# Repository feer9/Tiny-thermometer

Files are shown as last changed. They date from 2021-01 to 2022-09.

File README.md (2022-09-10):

# Tiny-thermomether

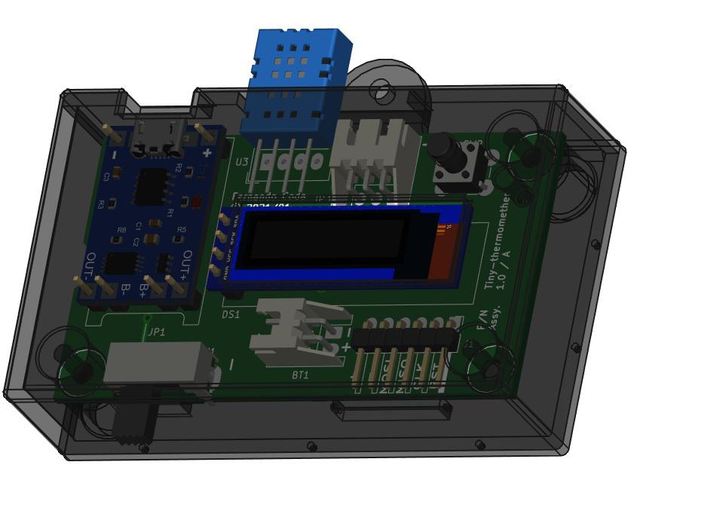
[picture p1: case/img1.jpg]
 

This project is mostly a recopilation of other projects I've found on various pages.  
I've just joined them at my personal taste, so I'll let the link to those projects below.  

## Parts used

+ ATtiny85
+ SSD1306 128x32 OLED I2C Display
+ DHT11 temperature and humidity sensor
+ DS18B20 water temperature sensor

## Electrical connection

ATtiny85  | PCB                   | Debug
--------- | --------------------- | --------
PB0       | Display SDA           | MOSI
PB1       | Push button           | MISO
PB2       | Display SCL           | CLK
PB3       | DHT11 (pin 2)         |
PB4       | DS18B20 (yellow wire) |
PB5       | N/C                   | RST

The sensors data lines have a 4.7K PullUp resistor.  
The push button have a 10K resistor.  
The I2C bus have a 10K PullUp resistor, both in SDA and SCL.

## Compilation and flashing

I've only tested it with avr-gcc on linux.  
To compile you need `avr-gcc` and `avr-g++`.  
To flash it I've used `avrdude` with an `usbasp-clone` avr programmer from [this other project](https://github.com/feer9/FASTUSBasp) running on an STM32F407VET6.  
Running `make flash` will compile and flash the program, but the first time you can `make install` to flash the program and fuses to match the clock speed.  

## Code included in this project:

https://www.instructables.com/ATTiny85-connects-to-I2C-OLED-display-Great-Things/

https://github.com/Jacajack/avr-ds18b20

https://www.hackster.io/boyanov/tinudht-c-library-for-dht11-temperature-humidity-sensor-c492e9

## Other pages of utility:

https://github.com/lexus2k/ssd1306

https://aprendiendoarduino.wordpress.com/2016/11/14/bus-i2ctwi/

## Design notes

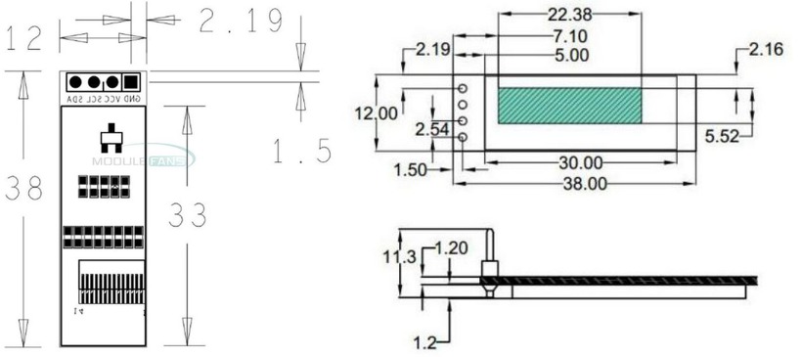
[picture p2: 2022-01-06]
pcb/doc/ssd1306_oled/oled_pcb_dimensions_2.jpeg

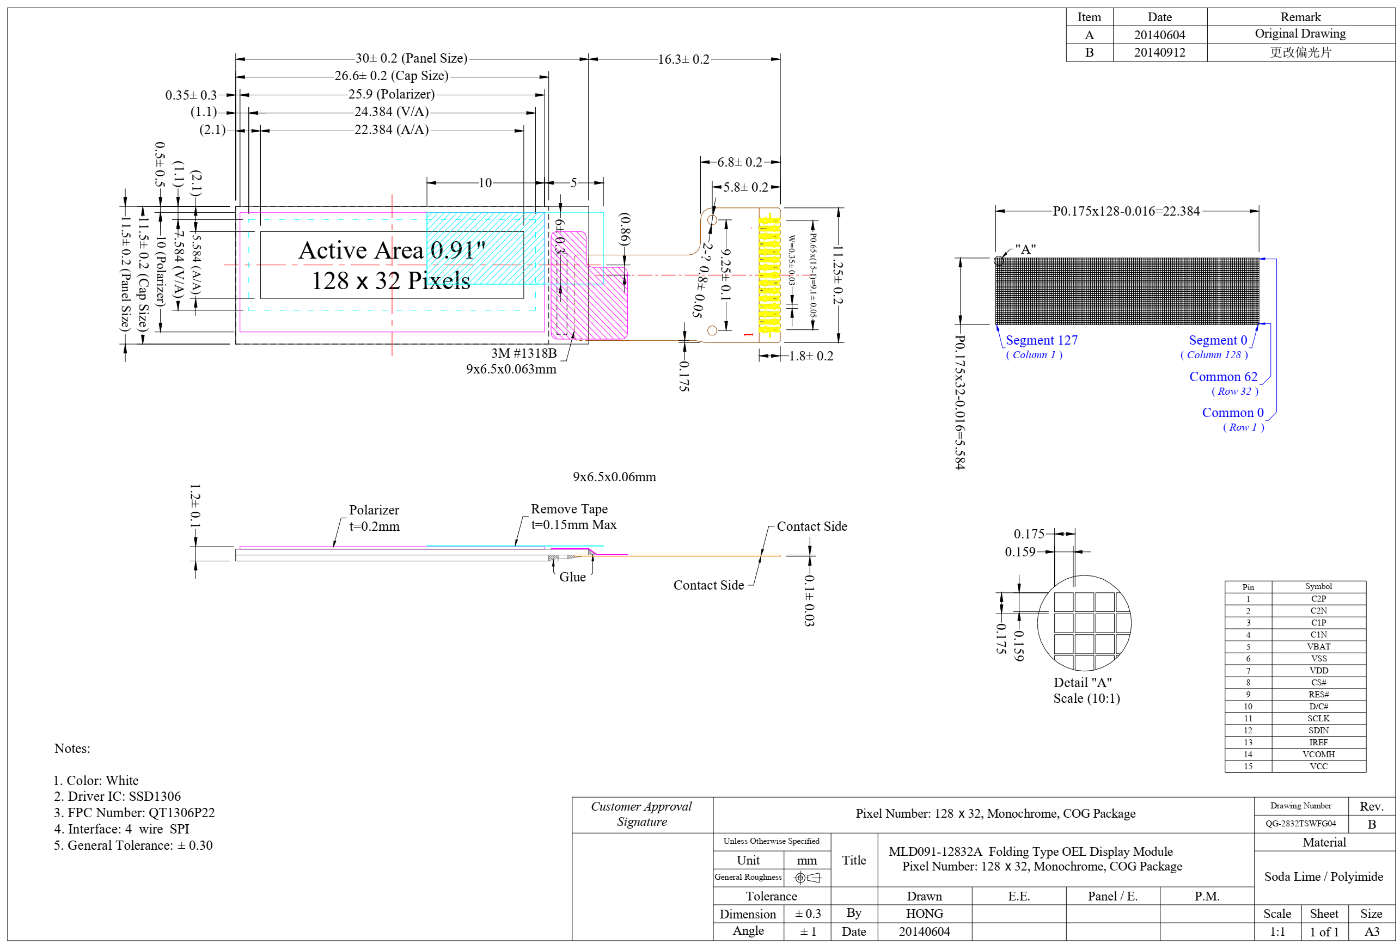
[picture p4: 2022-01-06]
pcb/doc/ssd1306_oled/oled_dimensions.png

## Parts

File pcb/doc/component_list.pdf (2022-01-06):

Tiny-thermomether

Source:
Date: | sáb 13 mar 2021 17:37:19
Tool: | Eeschema 5.1.9
Generator: | /usr/share/kicad/plugins/bom_csv_grouped_by_value.py

15

Individual Components:

Item | Qty | Reference(s) Value
BT1 | Battery_Cell
C1 | 0.1uF
DS1 | SSD1306_128x32
J1 | Conn_01x06_Male
R1 | 10k
R2 | 10k
R3 | 4k7
R4 | 4k7
R5 | 10k
SW1 | SW_SPDT
SW2 | SW_Push
U1 | TP4056
U2 | ATtiny85-20SU
U3 | DHT11
U4 | DS18B20

Collated Components:

Item | Qty | Reference(s) Value
1 | 1 | BT1 | Battery_Cell
2 | 1 | C1 | 0.1uF
3 | 1 | DS1 | SSD1306_128x32
4 | 1 | J1 | Conn_01x06_Male
5 | 3 | R1, R2, R5 10k
6 | 2 | R3, R4 | 4k7
7 | 1 | SW1 | SW_SPDT
8 | 1 | SW2 | SW_Push
9 | 1 | U1 | TP4056
10 | 1 | U2 | ATtiny85-20SU
11 | 1 | U3 | DHT11
12 | 1 | U4 | DS18B20

/run/media/Datos/Feer/OneDrive - est.frba.utn.edu.ar/pcbs/attiny85/Tiny-thermomether/Tiny-thermomether.sch

Component
Count:

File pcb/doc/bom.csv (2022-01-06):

Source: | /run/media/Datos/Feer/OneDrive - est.frba.utn.edu.ar/pcbs/attiny85/Tiny-thermomether/Tiny-thermomether.sch
Date: | sáb 13 mar 2021 17:37:19
Tool: | Eeschema 5.1.9
Generator: | /usr/share/kicad/plugins/bom_csv_grouped_by_value.py
Component Count: | 15
Individual Components:
Item | Qty | Reference(s) | Value | LibPart | Footprint | Datasheet
 |  | BT1 | Battery_Cell | Device:Battery_Cell | Connector_JST:JST_XH_S2B-XH-A_1x02_P2.50mm_Horizontal | ~
 |  | C1 | 0.1uF | Device:C | Capacitor_SMD:C_1206_3216Metric_Pad1.33x1.80mm_HandSolder | ~
 |  | DS1 | SSD1306_128x32 | ssd1306_128x32:SSD1306_128x32 | ssd1306:SSD1306_128x32 | https://www.digchip.com/datasheets/parts/datasheet/1121/AG-12864E-pdf.php
 |  | J1 | Conn_01x06_Male | Connector:Conn_01x06_Male | Connector_PinHeader_2.54mm:PinHeader_1x06_P2.54mm_Horizontal | ~
 |  | R1 | 10k | Device:R | Resistor_SMD:R_1206_3216Metric_Pad1.30x1.75mm_HandSolder | ~
 |  | R2 | 10k | Device:R | Resistor_SMD:R_1206_3216Metric_Pad1.30x1.75mm_HandSolder | ~
 |  | R3 | 4k7 | Device:R | Resistor_SMD:R_1206_3216Metric_Pad1.30x1.75mm_HandSolder | ~
 |  | R4 | 4k7 | Device:R | Resistor_SMD:R_1206_3216Metric_Pad1.30x1.75mm_HandSolder | ~
 |  | R5 | 10k | Device:R | Resistor_SMD:R_1206_3216Metric_Pad1.30x1.75mm_HandSolder | ~
 |  | SW1 | SW_SPDT | Switch:SW_SPDT | Button_Switch_THT:SW_SPDT_Angled_P3mm_13x5.5x6mm | ~
 |  | SW2 | SW_Push | Switch:SW_Push | Button_Switch_THT:SW_PUSH_6mm_H7.3mm | ~
 |  | U1 | TP4056 | tp4056:TP4056 | tp4056:TP4056
 |  | U2 | ATtiny85-20SU | MCU_Microchip_ATtiny:ATtiny85-20SU | Package_SO:SOIJ-8_5.3x5.3mm_P1.27mm | http://ww1.microchip.com/downloads/en/DeviceDoc/atmel-2586-avr-8-bit-microcontroller-attiny25-attiny45-attiny85_datasheet.pdf
 |  | U3 | DHT11 | Sensor:DHT11 | Sensor:Aosong_DHT11_5.5x12.0_P2.54mm_horizontal | http://akizukidenshi.com/download/ds/aosong/DHT11.pdf
 |  | U4 | DS18B20 | Sensor_Temperature:DS18B20 | Connector_JST:JST_XH_S3B-XH-A_1x03_P2.50mm_Horizontal | http://datasheets.maximintegrated.com/en/ds/DS18B20.pdf
Collated Components:
Item | Qty | Reference(s) | Value | LibPart | Footprint | Datasheet
1 | 1 | BT1 | Battery_Cell | Device:Battery_Cell | Connector_JST:JST_XH_S2B-XH-A_1x02_P2.50mm_Horizontal | ~
2 | 1 | C1 | 0.1uF | Device:C | Capacitor_SMD:C_1206_3216Metric_Pad1.33x1.80mm_HandSolder | ~
3 | 1 | DS1 | SSD1306_128x32 | ssd1306_128x32:SSD1306_128x32 | ssd1306:SSD1306_128x32 | https://www.digchip.com/datasheets/parts/datasheet/1121/AG-12864E-pdf.php
4 | 1 | J1 | Conn_01x06_Male | Connector:Conn_01x06_Male | Connector_PinHeader_2.54mm:PinHeader_1x06_P2.54mm_Horizontal | ~
5 | 3 | R1, R2, R5 | 10k | Device:R | Resistor_SMD:R_1206_3216Metric_Pad1.30x1.75mm_HandSolder | ~
6 | 2 | R3, R4 | 4k7 | Device:R | Resistor_SMD:R_1206_3216Metric_Pad1.30x1.75mm_HandSolder | ~
7 | 1 | SW1 | SW_SPDT | Switch:SW_SPDT | Button_Switch_THT:SW_SPDT_Angled_P3mm_13x5.5x6mm | ~
8 | 1 | SW2 | SW_Push | Switch:SW_Push | Button_Switch_THT:SW_PUSH_6mm_H7.3mm | ~
9 | 1 | U1 | TP4056 | tp4056:TP4056 | tp4056:TP4056
10 | 1 | U2 | ATtiny85-20SU | MCU_Microchip_ATtiny:ATtiny85-20SU | Package_SO:SOIJ-8_5.3x5.3mm_P1.27mm | http://ww1.microchip.com/downloads/en/DeviceDoc/atmel-2586-avr-8-bit-microcontroller-attiny25-attiny45-attiny85_datasheet.pdf
11 | 1 | U3 | DHT11 | Sensor:DHT11 | Sensor:Aosong_DHT11_5.5x12.0_P2.54mm_horizontal | http://akizukidenshi.com/download/ds/aosong/DHT11.pdf
12 | 1 | U4 | DS18B20 | Sensor_Temperature:DS18B20 | Connector_JST:JST_XH_S3B-XH-A_1x03_P2.50mm_Horizontal | http://datasheets.maximintegrated.com/en/ds/DS18B20.pdf

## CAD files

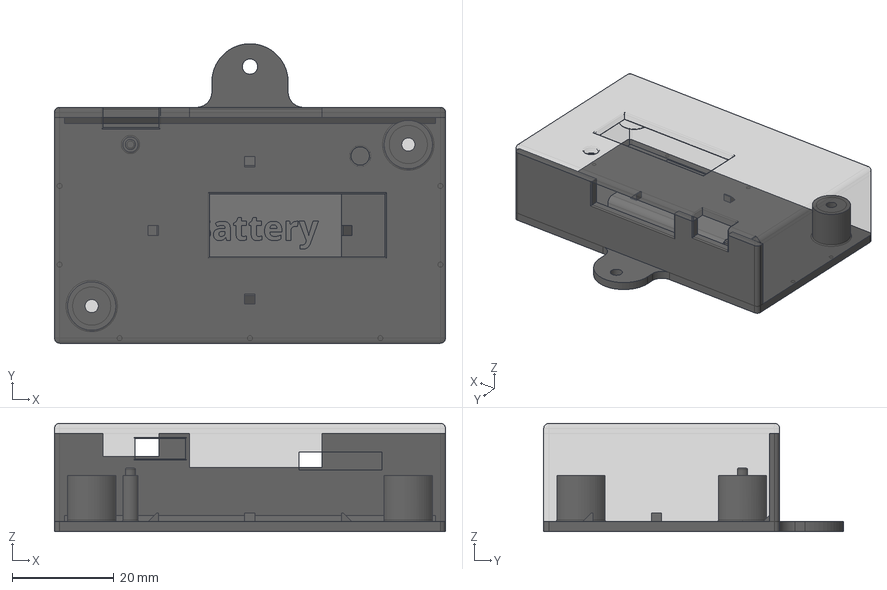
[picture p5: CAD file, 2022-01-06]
case/case.FCStd
76.9 x 58.9 x 21.3 mm
Tapa
Battery
Base

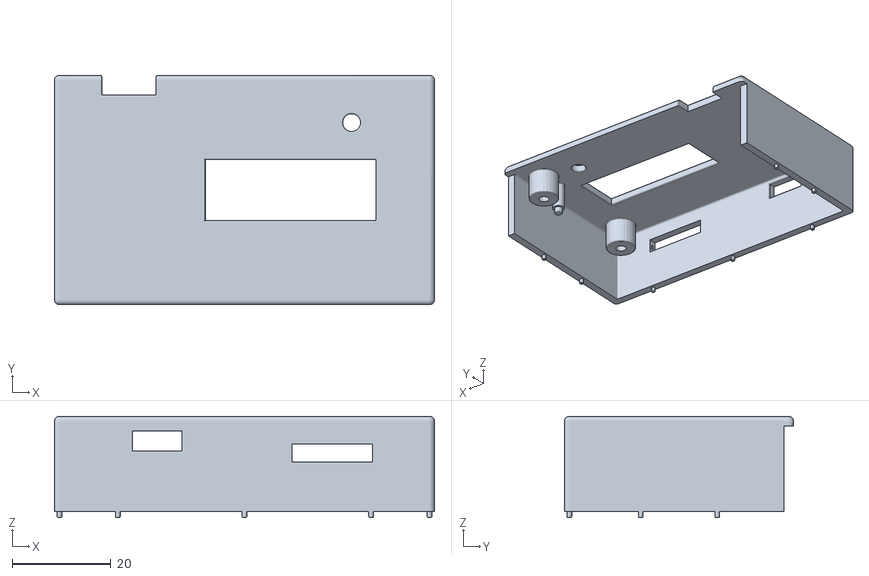
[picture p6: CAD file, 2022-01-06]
case/imprimibles/tapa.stl
76.9 x 46.4 x 20.5

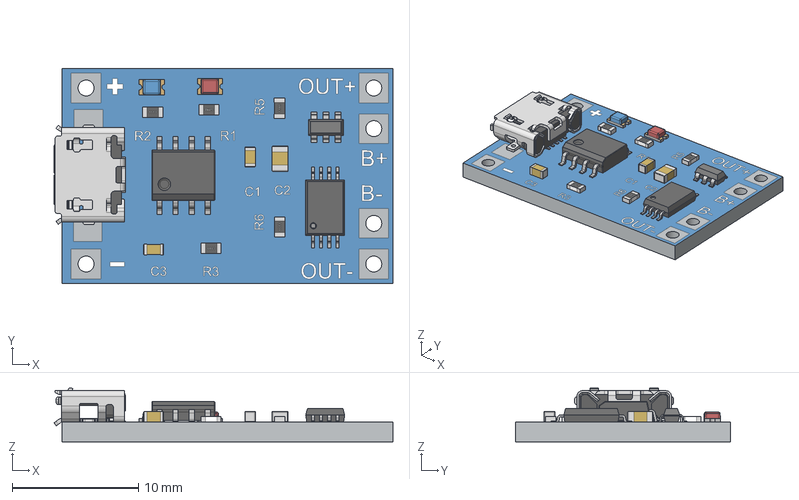
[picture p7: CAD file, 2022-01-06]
pcb/footprints/3dmodels/tp4056.stp
26.9 x 17.1 x 4.28 mm
bOARD
0603 Capacitor x 2
0603 Resistor x 5
0805 Capacitor
SOIC-8-150
LED - 0805 - Blue
LED - 0805 - Red
USB - Micro
tsop8
sot-23-6-2

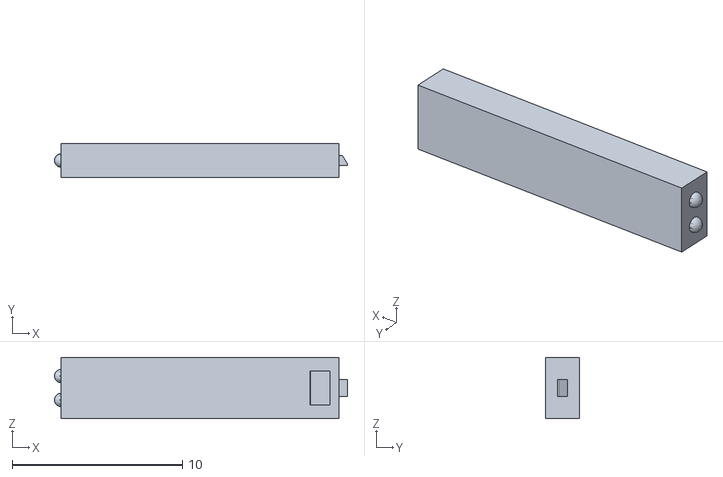
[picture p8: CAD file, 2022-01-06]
case/imprimibles/tapita.stl
17.2 x 2.00 x 3.60

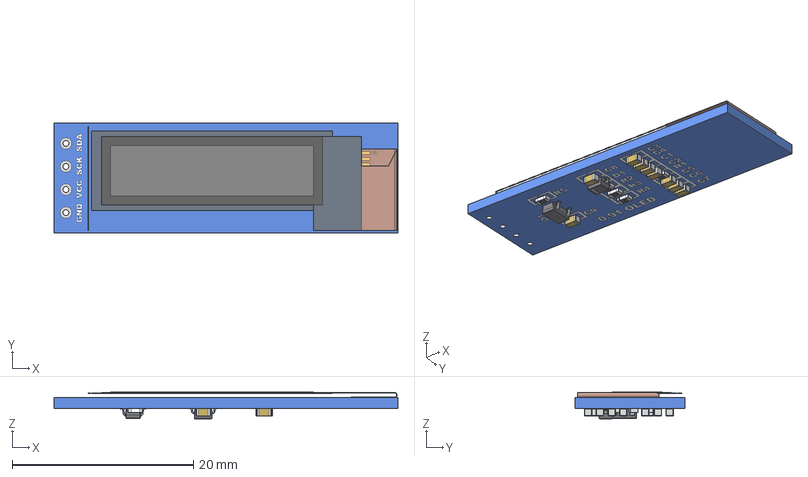
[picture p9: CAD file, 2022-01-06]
pcb/footprints/3dmodels/ssd1306_0.91.stp
37.9 x 12.1 x 2.93 mm
0.91in oled Module - Board
0.91in OLED - Folded Flush - Without Glass
0603 Capacitor x 9
0603 Resistor x 5
SOT23-3
Diode (SOD-323)

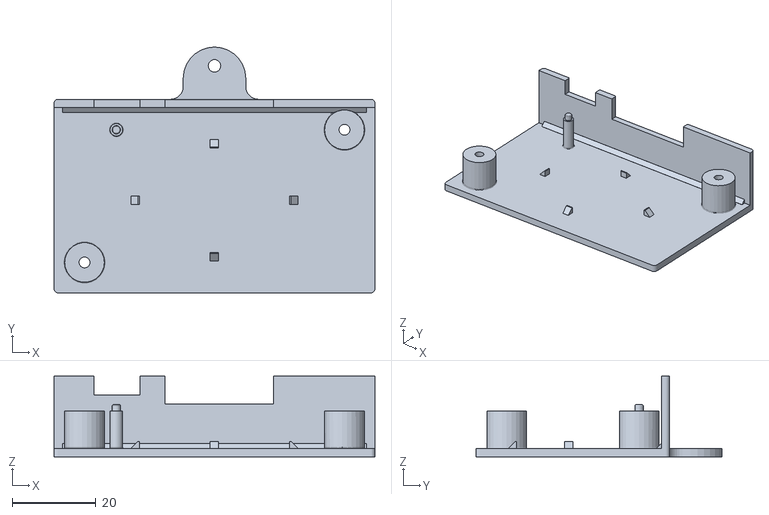
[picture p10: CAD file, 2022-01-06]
case/imprimibles/base.stl
76.9 x 58.9 x 19.3

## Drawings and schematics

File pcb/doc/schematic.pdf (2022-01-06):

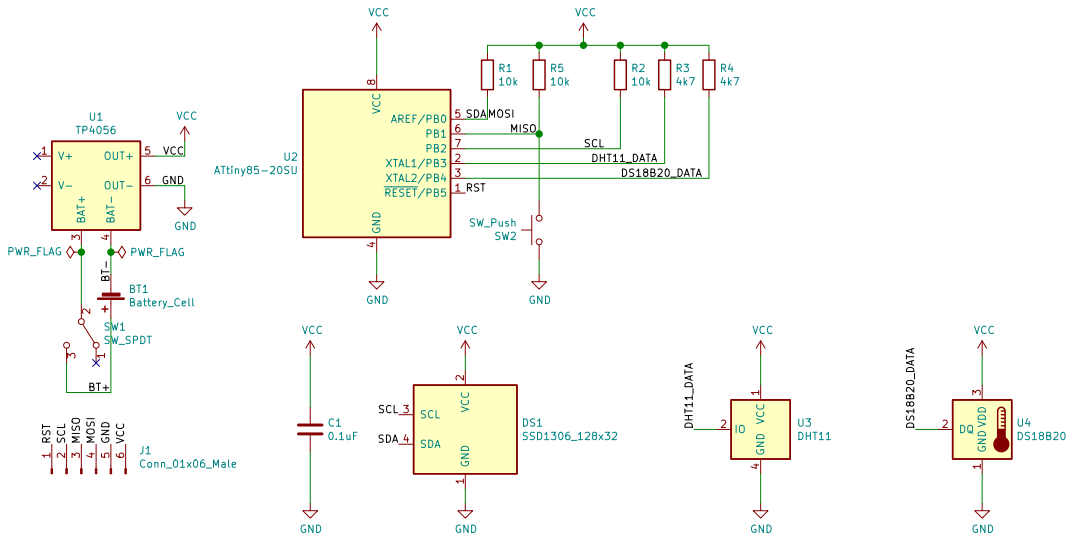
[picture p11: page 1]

SCL MISO MOSI SCL MISO MOSI GND

3 BAT- 4 OUT+ 5 OUT- 6 U1 TP4056 BT1 Battery_Cell SW2 SW_Push GND

File: Tiny-thermomether.sch Sheet: / Fernando Coda

Id: 1/1 Title: Tiny-Thermometer

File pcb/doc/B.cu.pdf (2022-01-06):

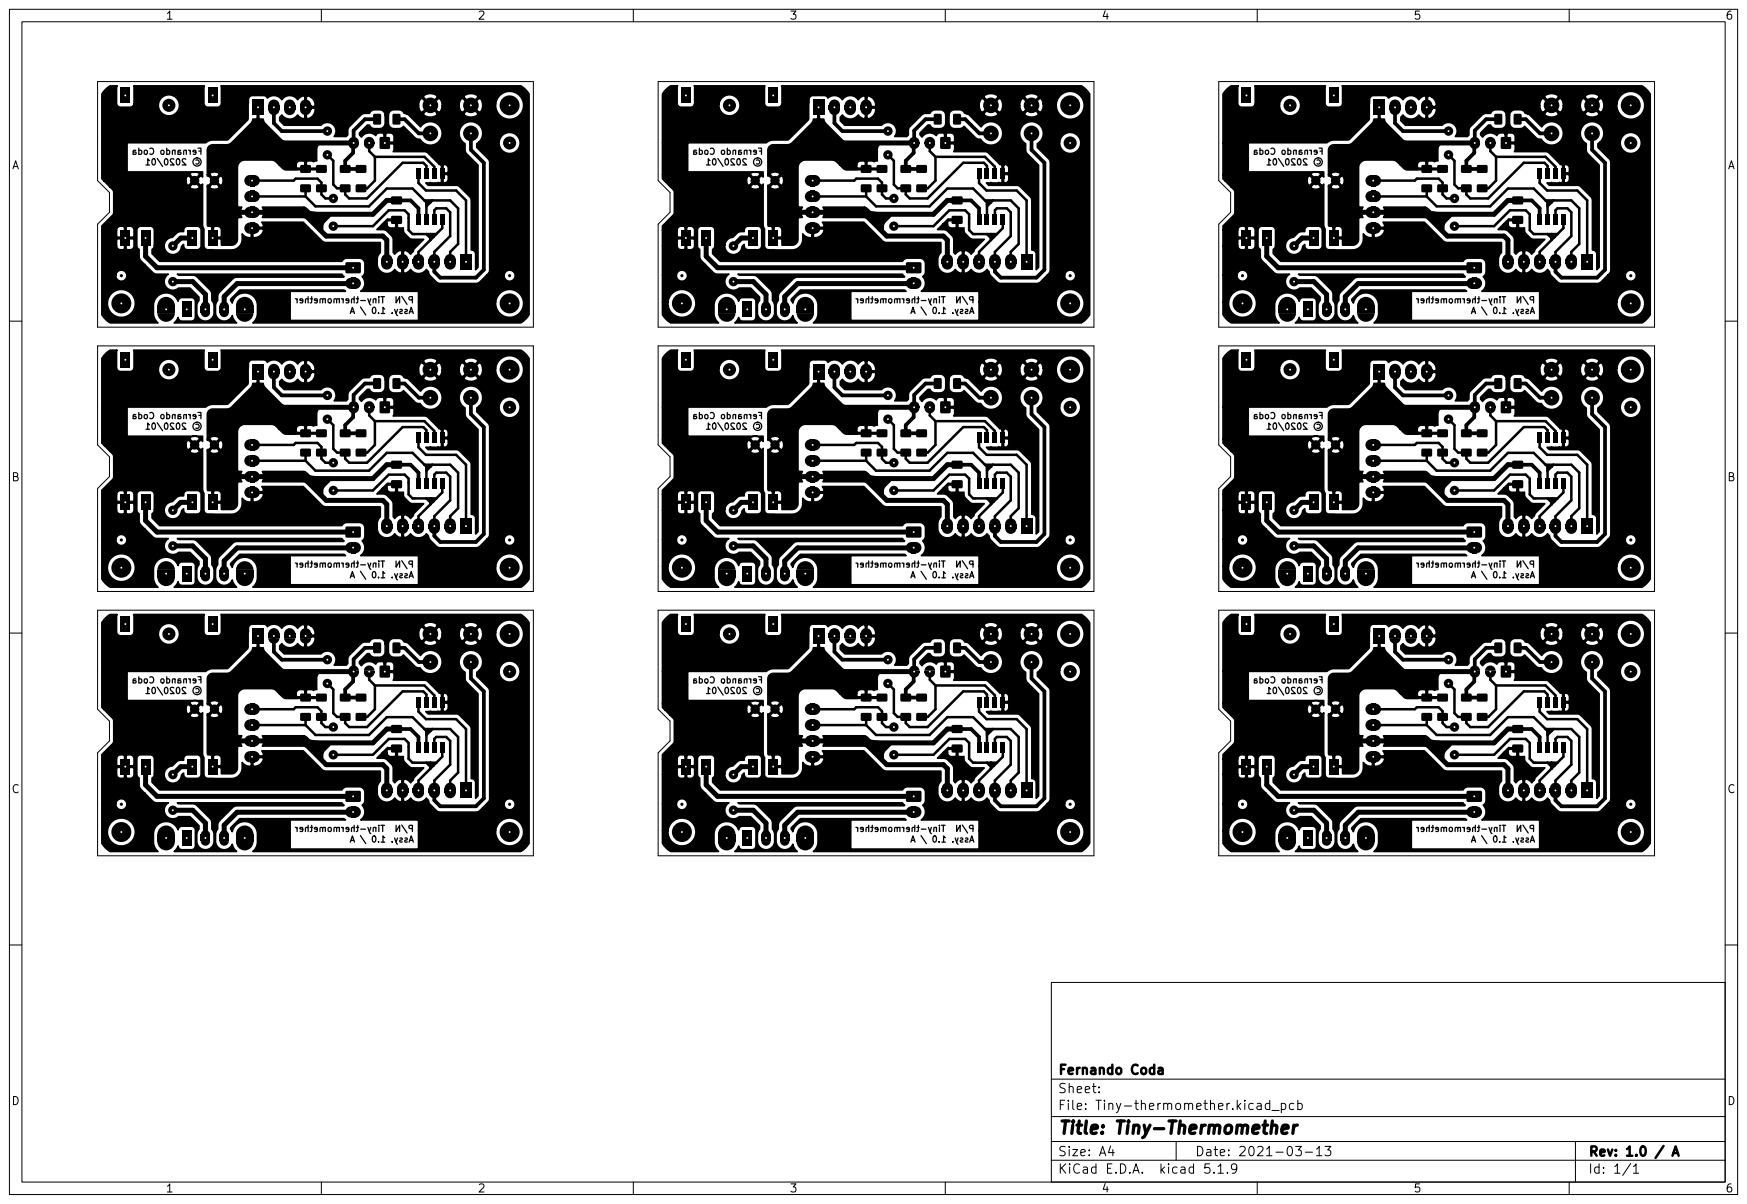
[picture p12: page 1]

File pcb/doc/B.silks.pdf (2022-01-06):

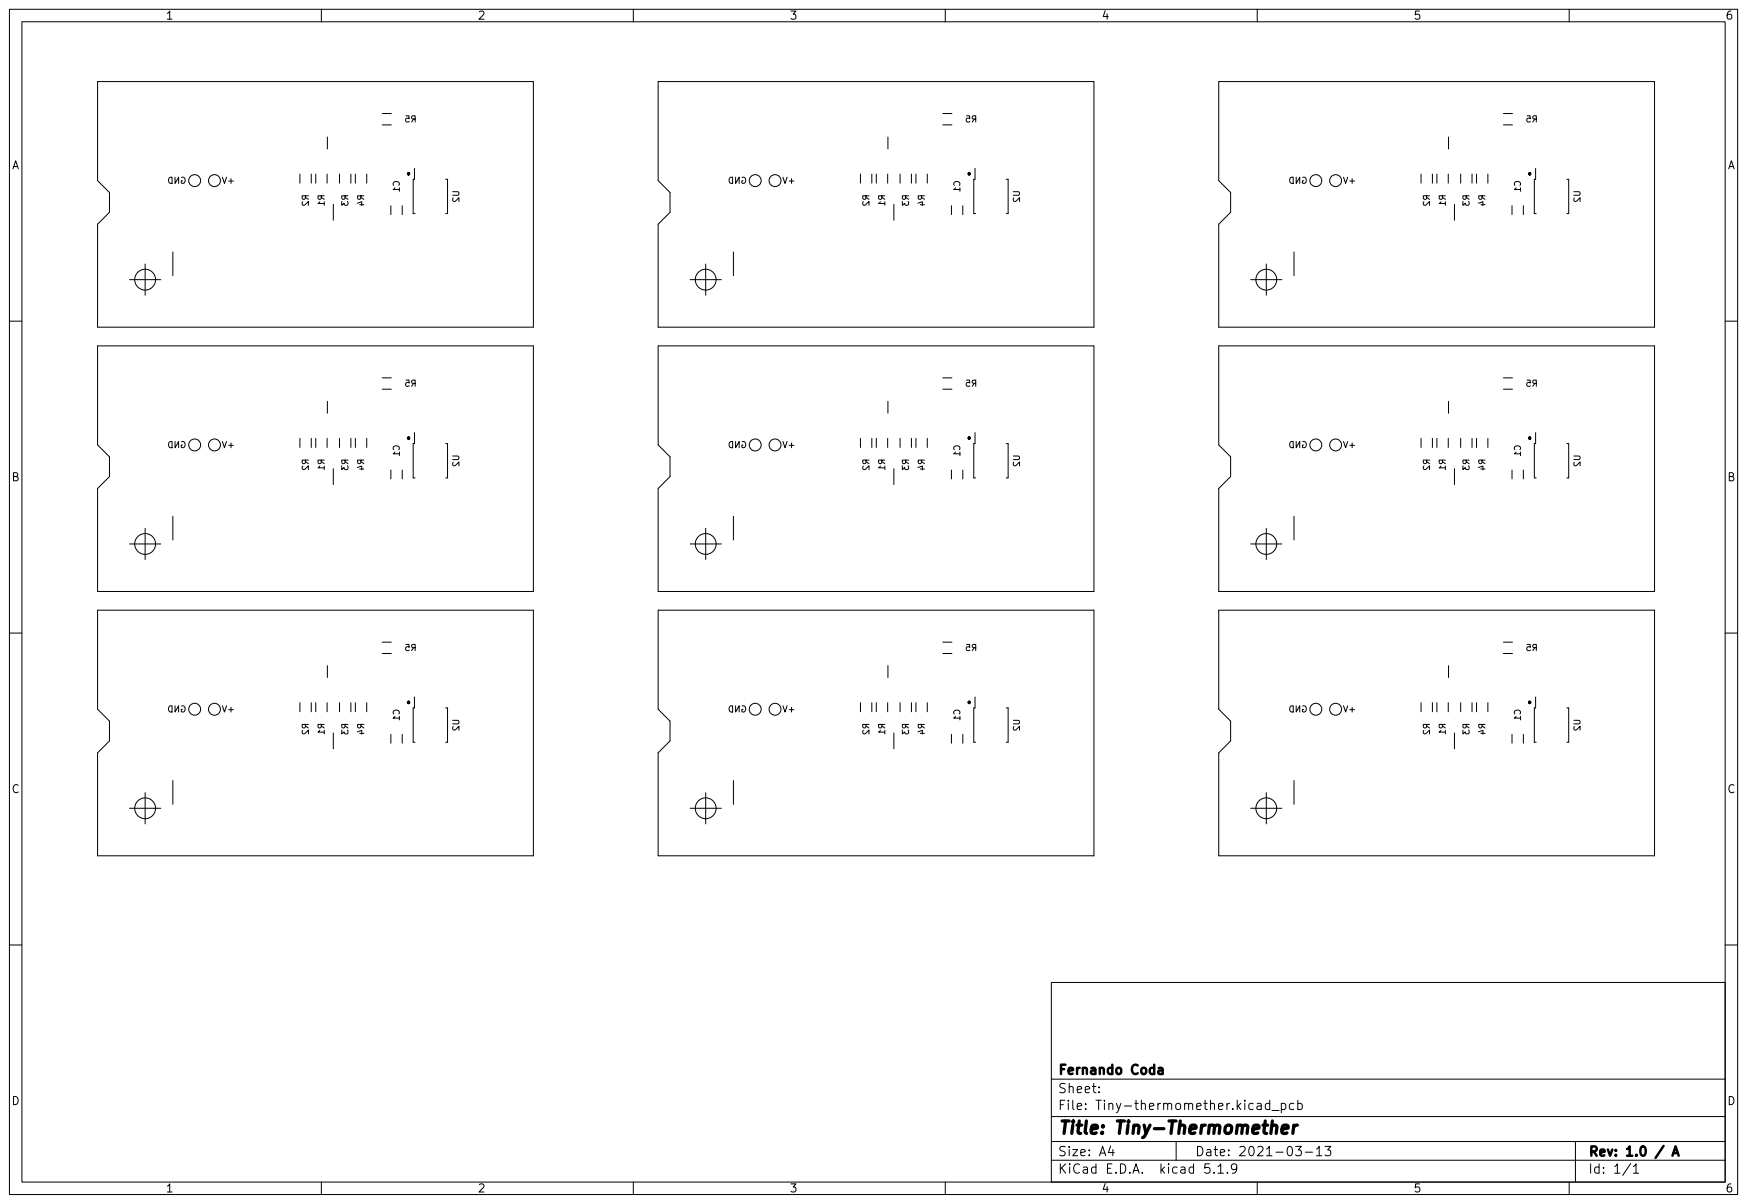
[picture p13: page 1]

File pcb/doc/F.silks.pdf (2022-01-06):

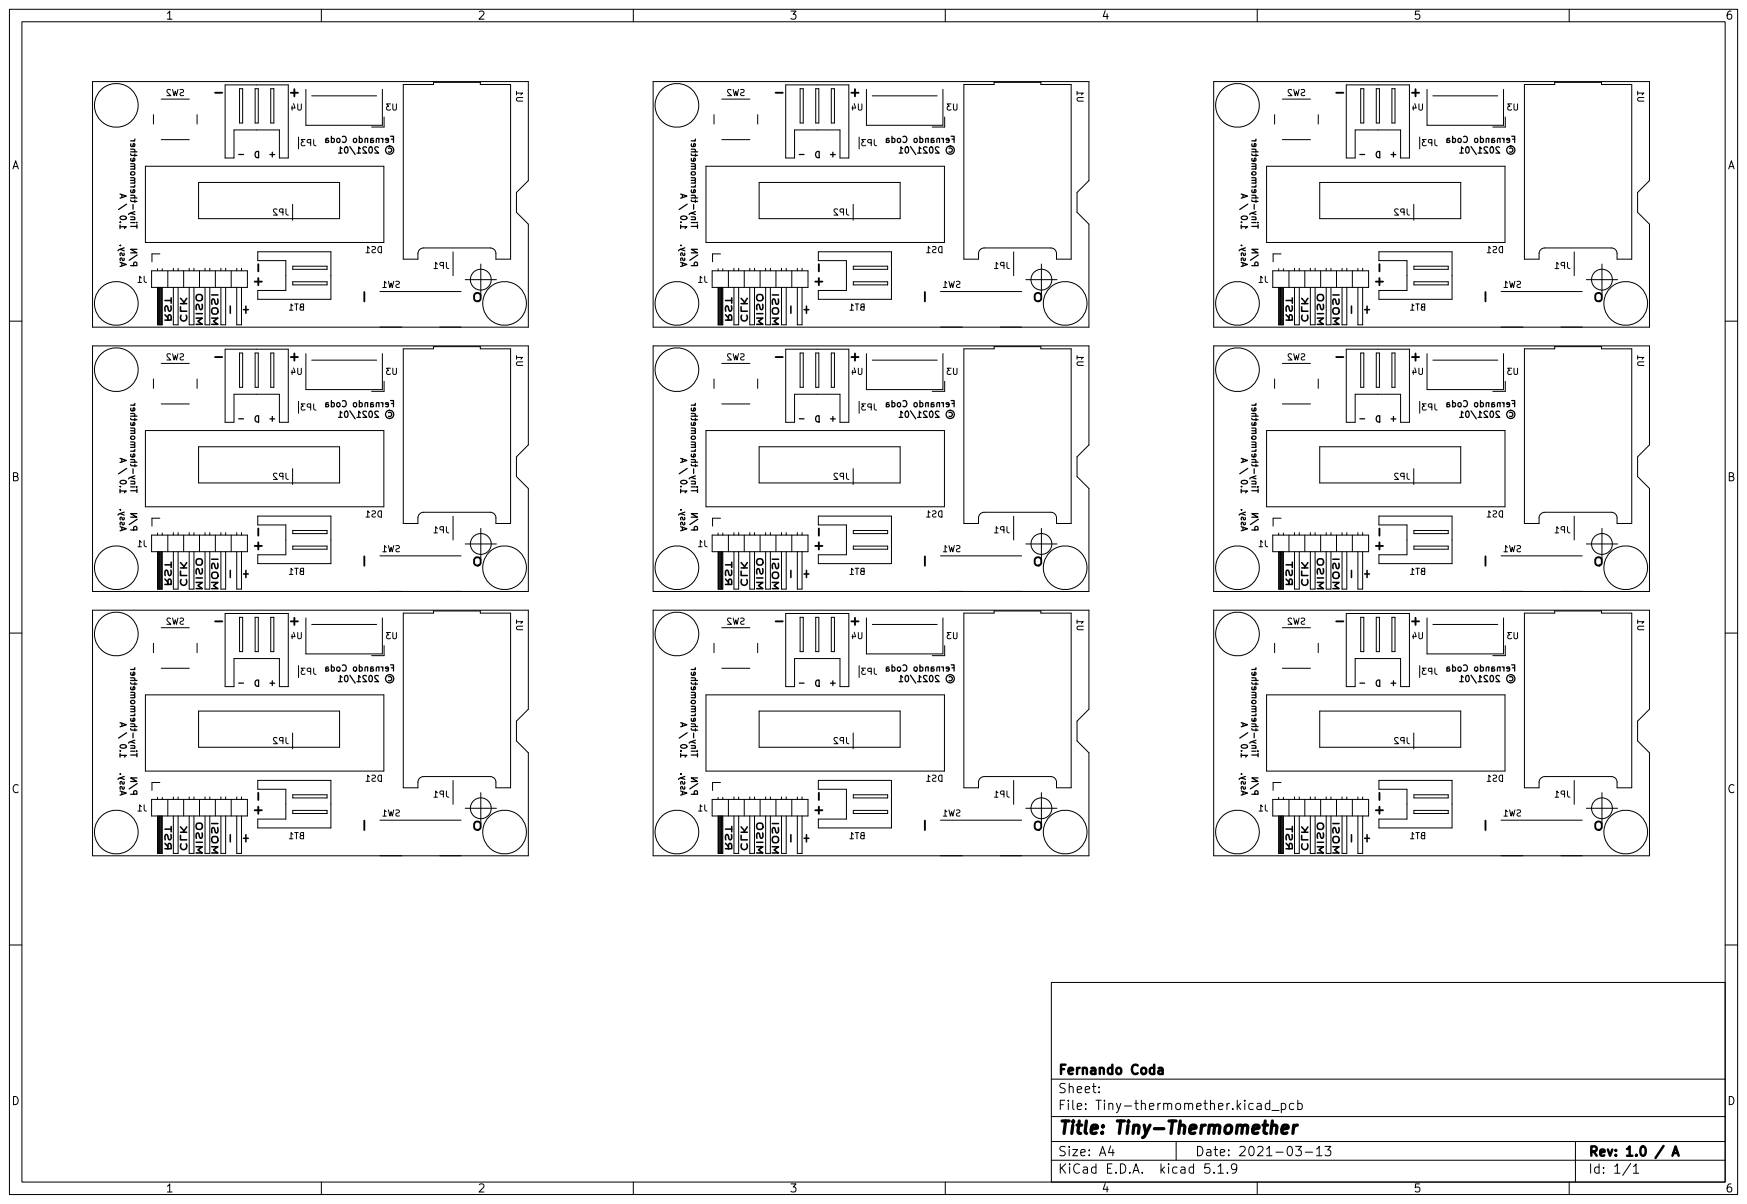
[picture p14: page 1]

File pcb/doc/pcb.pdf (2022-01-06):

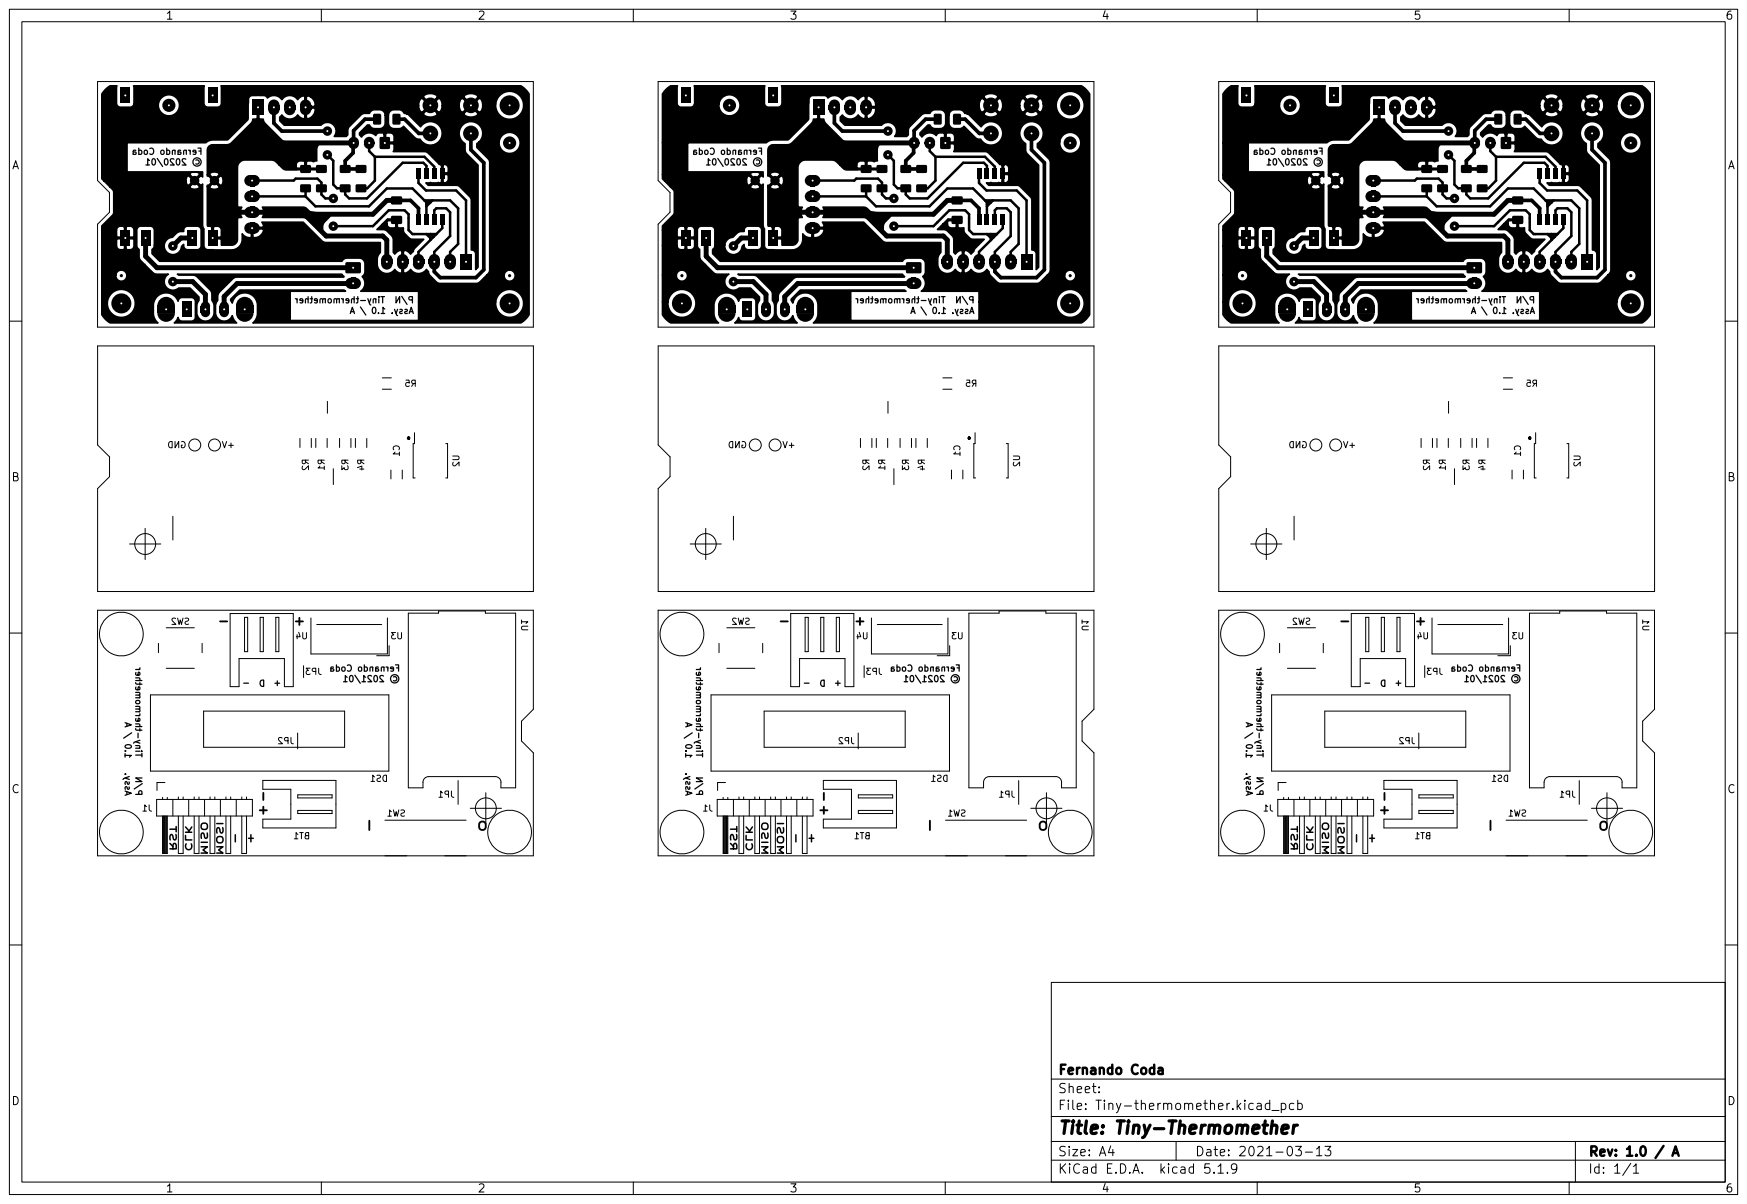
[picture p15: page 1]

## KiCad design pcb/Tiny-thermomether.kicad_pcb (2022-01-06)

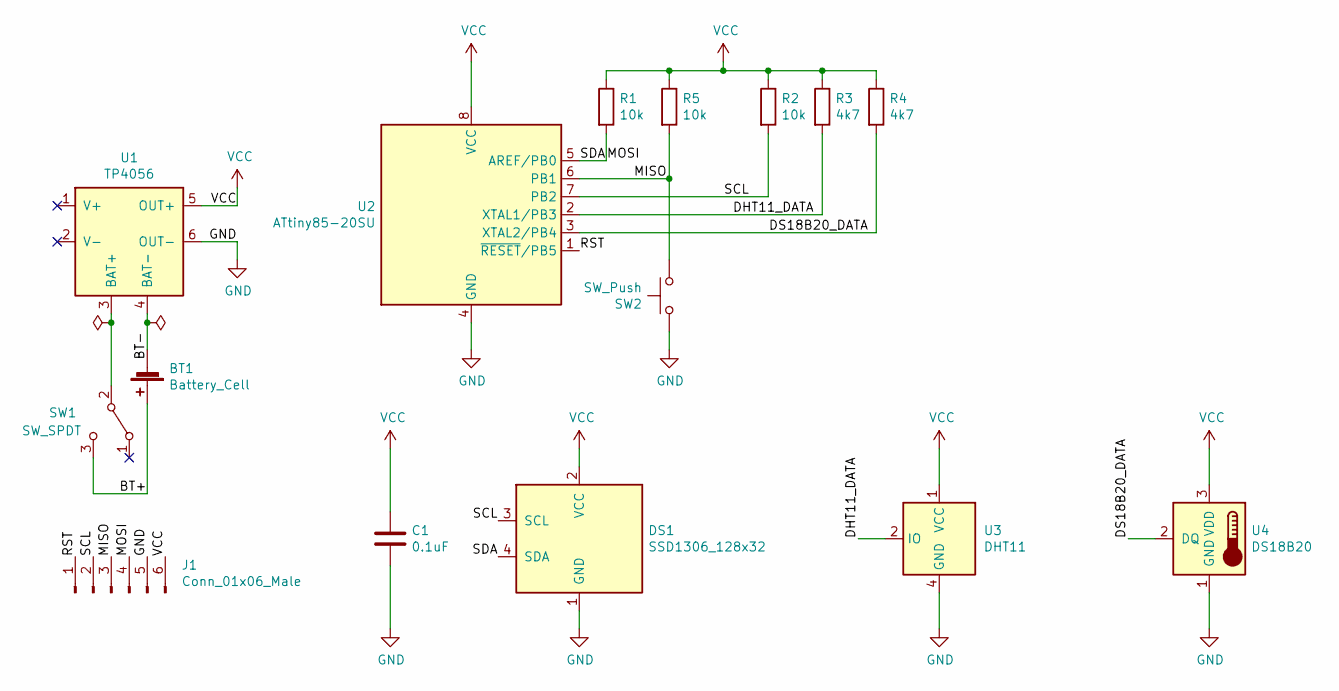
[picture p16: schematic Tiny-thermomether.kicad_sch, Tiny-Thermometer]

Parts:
BT1: Battery_Cell; JST_XH_S2B-XH-A_1x02_P2.50mm_Horizontal
C1: 0.1uF; C_1206_3216Metric_Pad1.33x1.80mm_HandSolder
DS1: SSD1306_128x32
J1: Conn_01x06_Male; PinHeader_1x06_P2.54mm_Horizontal
R1, R2, R5: 10k; R_1206_3216Metric_Pad1.30x1.75mm_HandSolder
R3, R4: 4k7; R_1206_3216Metric_Pad1.30x1.75mm_HandSolder
SW1: SW_SPDT; SW_SPDT_Angled_P3mm_13x5.5x6mm
SW2: SW_Push; SW_PUSH_6mm_H7.3mm
U1: TP4056
U2: ATtiny85-20SU; SOIJ-8_5.3x5.3mm_P1.27mm
U3: DHT11; Aosong_DHT11_5.5x12.0_P2.54mm_horizontal
U4: DS18B20; JST_XH_S3B-XH-A_1x03_P2.50mm_Horizontal

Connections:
/BT+: BT1.1 (+), SW1.3 (C)
/BT-: BT1.2 (-), U1.4 (BAT-)
/DHT11_DATA: R3.2, U2.2 (XTAL1/PB3), U3.2 (IO)
/DS18B20_DATA: R4.2, U2.3 (XTAL2/PB4), U4.2 (DQ)
/MISO: J1.3, R5.2, SW2.2, U2.6 (PB1)
/MOSI: DS1.4 (SDA), J1.4, R1.2, U2.5 (AREF/PB0)
/RST: J1.1, U2.1 (~RESET/PB5)
/SCL: DS1.3 (SCL), J1.2, R2.2, U2.7 (PB2)
GND: C1.2, DS1.1 (GND), J1.5, SW2.1, U1.6 (OUT-), U2.4 (GND), U3.4 (GND), U4.1 (GND); also elsewhere on the board
unnamed: SW1.2 (B), U1.3 (BAT+)
VCC: C1.1, DS1.2 (VCC), J1.6, R1.1, R2.1, R3.1, R4.1, R5.1, U1.5 (OUT+), U2.8 (VCC), U3.1 (VCC), U4.3 (VDD); also elsewhere on the board

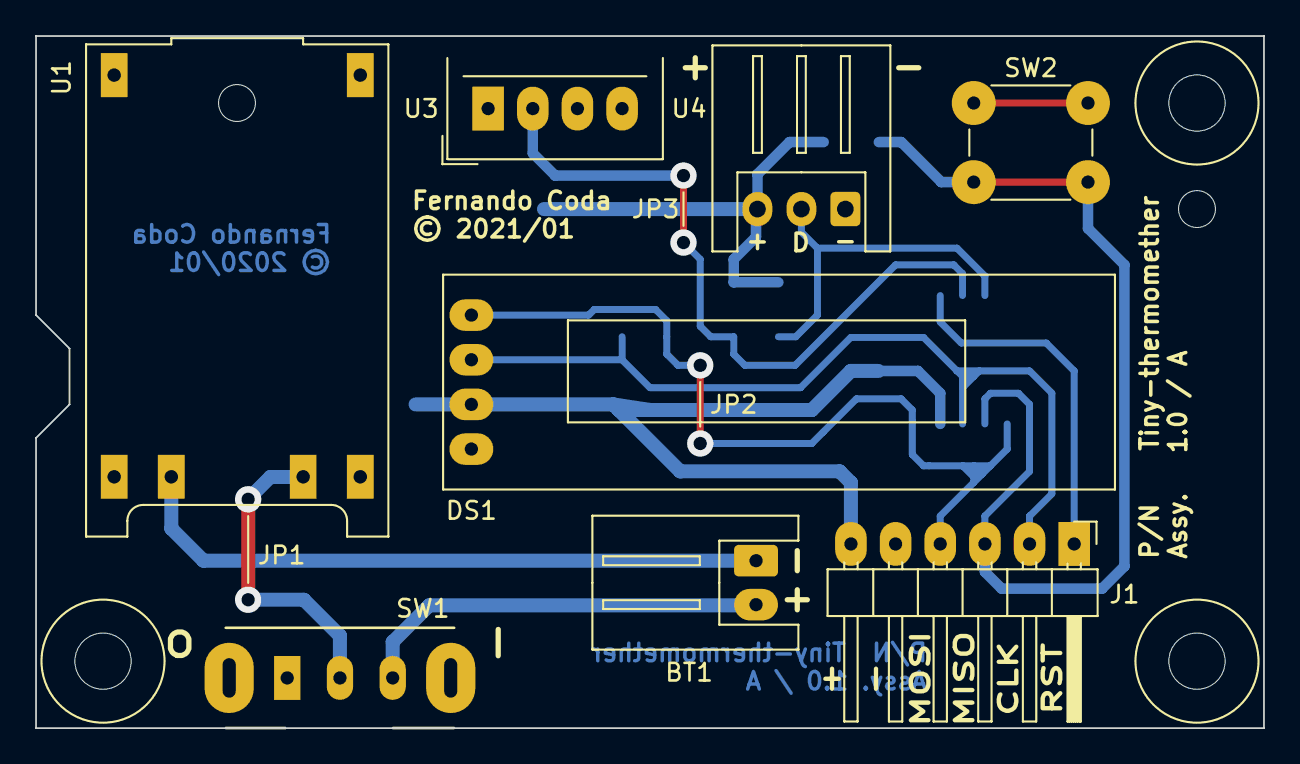
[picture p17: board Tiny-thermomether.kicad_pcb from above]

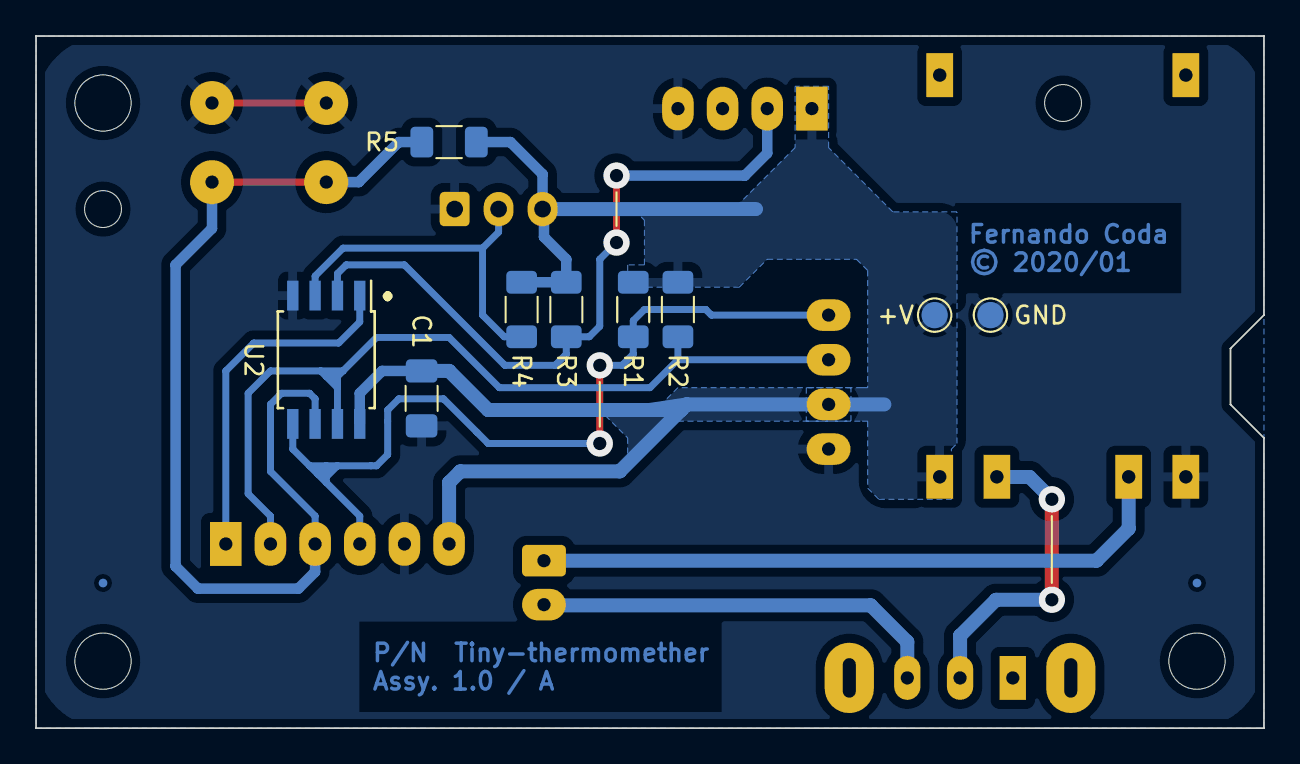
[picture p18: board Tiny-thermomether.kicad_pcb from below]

Board: 2 copper layers, 69.9 x 39.4 mm, 17 parts (9 on the bottom side), 11 nets.

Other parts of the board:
+V: TestPoint_Pad_D1.5mm
GND: TestPoint_Pad_D1.5mm

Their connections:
GND: GND.1; also elsewhere on the board
VCC: +V.1; also elsewhere on the board

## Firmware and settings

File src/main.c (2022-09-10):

#include "app.h"
#include <avr/wdt.h>

static void readButton(void);
static void endLoop(void);

/* Attiny85 PINS:

PB0: MOSI SDA
PB1: MISO
PB2:      SCL
PB3: 
PB4: 
PB5: Reset
*/

// TODO: ensure lowest frequency to reduce consumption
//       can't get too low since the display doesn't appear to like it

//__attribute__ ((address (0x1234)))

static uint32_t last_activity = 0;



static void endLoop(void)
{
	uint32_t T_inactive = (get_tick()-last_activity);
	uint8_t sleepmode;

	if(T_inactive <= LONG_PRESS_TIME)
		return;
	
	if(getScreenState() == SCREEN_OFF && T_inactive > 5000) {
		// Sleep until an external interrupt
		sleepmode = SLEEP_MODE_PWR_DOWN;
	}
	else if(T_inactive > 1000*60*5) {
		// Turn screen OFF and sleep until an external interrupt
		screenOFF();
		sleepmode = SLEEP_MODE_PWR_DOWN;
	}
	else {
		// Sleep until a timer interrupt
		sleepmode = SLEEP_MODE_IDLE;
	}
	
	cli();
	set_sleep_mode(sleepmode);
	sleep_enable();
	if (sleepmode == SLEEP_MODE_PWR_DOWN)
		sleep_bod_disable();
	sei();
	sleep_cpu();
	sleep_disable();
}

// Basic debounce function based on an Arduino example
static void readButton(void)
{
	static uint8_t button_st = BUTTON_RELEASED;
	static uint8_t last_reading = BUTTON_RELEASED;
	static uint32_t T_last_change = 0; // time in which the last state change happened
	static bool longpressed = false;
	uint32_t elapsed;                  // time elapsed since last state change
	uint8_t curr_reading = pin_get(BUTTON_PIN);
	const uint32_t curr_tick = get_tick();

	// If the switch changed, due to noise or pressing:
	if(curr_reading != last_reading) {
		// reset the debouncing timer
		T_last_change = curr_tick;
	}

	elapsed = curr_tick-T_last_change;
	if(elapsed > DEBOUNCE_DELAY)
	{
		// whatever the reading is at, it's been there for longer than
		// the debounce delay, so take it as the actual current state:

		// if the button state has changed:
		if(curr_reading != button_st)
		{	
			button_st = curr_reading;
			last_activity = curr_tick;

			if(curr_reading == BUTTON_RELEASED && elapsed < LONG_PRESS_TIME && !longpressed) {
				buttonSimpleAction();
			}

			longpressed   = false;
		}
		else if(curr_reading == BUTTON_PRESSED && !longpressed && elapsed >= LONG_PRESS_TIME)
		{
			longpressed = true;
			buttonLongPressed();
		}
	}

	last_reading = curr_reading;
}

ISR(PCINT0_vect)
{
	last_activity = get_tick();
}

static void enable_interrupts(void)
{
	// Turn on external interrupts on BUTTON_PIN
	//  BUTTON_PIN = PB1 = PCINT1

	// Set Pin Change Interrupt Enable on General Interrupt Mask Register
	GIMSK = (1 << PCIE);
	// Enable Pin Change Interrupt on PB1
	PCMSK |= (1 << PCINT1);

	// Enable Global Interrupt
	sei();
}

static void GPIO_init(void)
{
	pinmode_input(BUTTON_PIN);
	pinmode_pullup_off(BUTTON_PIN);
}

static void WDT_off(void)
{
	wdt_reset();
	/* Clear WDRF in MCUSR */
	MCUSR = 0x00;
	/* Write logical one to WDCE and WDE */
	WDTCR |= (1<<WDCE) | (1<<WDE);
	/* Turn off WDT */
	WDTCR = 0x00;
}

static void power_management(void)
{
	// Turn off Analog Comparator
	ACSR = (1 << ACD);
	// Shut down Timer1 and ADC
	PRR  = (1 << PRTIM1) | (1 << PRADC);

	// Turn off Watch Dog Timer
	WDT_off();
}

void uC_init(void)
{
	GPIO_init();

	// Stop interrupts
    cli();

	Timer0_init();

	power_management();

	enable_interrupts();

	appSetup();
}

void main (void)
{
	uC_init();

	for(;;) {
		readButton();

		appLoop();

		endLoop();
	}
}

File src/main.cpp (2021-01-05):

#include "utils.h"
#include "tinudht.h"
#include <ds18b20/ds18b20.h>
#include "SSD1306_minimal.h"
#include <avr/pgmspace.h>
#include <avr/sleep.h>

#define delay(x) _delay_ms(x)
#define LED_PIN  tiny_led

/* Attiny85 PINS:

PB0: MOSI SDA
PB1: MISO
PB2:      SCL
PB3: 
PB4: 
PB5: Reset
*/

#define DEG "\xa7" "C"

static SSD1306_Mini oled;
static const uint8_t ds18b20_pinMask = (1 << DS18B20_PIN);

//byte array of bitmap 5x24px
static const unsigned char  img_thermometer_cold[] PROGMEM = {
  0x00, 0xfe, 0x03, 0xfe, 0x50,
  0x00, 0xff, 0x00, 0xff, 0x55,
  0x60, 0x9f, 0x80, 0x9f, 0x65
};

//byte array of bitmap 5x24px
static const unsigned char  img_thermometer_warm[] PROGMEM = {
  0x00, 0xfe, 0x03, 0xfe, 0x50,
  0x00, 0xff, 0x00, 0xff, 0x55,
  0x60, 0xff, 0xff, 0xff, 0x65
};

//byte array of bitmap 5x24px
static const unsigned char  img_thermometer_hot[] PROGMEM = {
  0x00, 0xfe, 0x03, 0xfe, 0x50,
  0x00, 0xff, 0xff, 0xff, 0x55,
  0x60, 0xff, 0xff, 0xff, 0x65
};

void prepareDisplay() {

  oled.clear();
  oled.startScreen();

  oled.drawImage( img_thermometer_cold, 5,1, 5, 3 );

  oled.printStringTo(20, 1, "Water: -");
  oled.printStringTo(20, 2, "Room:  -");
  oled.printStringTo(20, 3, "Hum.:  -");
}

void setup(){
  pinmode_output(LED_PIN);
  pin_clear(LED_PIN);

  oled.init(SlaveAddress);

  prepareDisplay();

	_delay_ms(200);	// Delay for DHT11 to stabilize (REQUIRED on power on)
  ds18b20wsp( &PORTB, &DDRB, &PINB, ds18b20_pinMask, NULL, 100, 0, DS18B20_RES11);

  Timer0_init();
  
  ACSR = _BV(ACD); // Turn off Analog Comparator
  PRR = _BV(PRTIM1) | _BV(PRADC); // Shut down Timer1 and ADC
}

void loop() {

  static TinuDHT tinudht;
  static uint8_t tinudht_status;
  static uint8_t tinudht_last_temp = 0, tinudht_last_hum = 0;

  static ifloat32_t ds18b20;
  static ifloat32_t ds18b20_last;
  static uint8_t ds18b20_status = DS18B20_OK;
  
  static uint32_t t1=0, t2=0, t3=0;
  uint32_t tick = get_tick();

  if(tick > t1) { // update ds18b20
    t1 = tick+250;
    pin_set(tiny_led); 
    
    // Read ds18b20 data
    ds18b20_status = ds18b20convert_read( &PORTB, &DDRB, &PINB, ds18b20_pinMask, NULL, ds18b20 );
    
    if(ds18b20_status != DS18B20_OK) {
      oled.printStringTo(68, 1, _ERR_MSG);
    }
    else if( ds18b20_last != ds18b20 )
    {
      ds18b20_last = ds18b20;
      oled.printFloatTo(68,1, ds18b20);
      oled.printStringTo(UNITS_POSITION, 1, DEG);
    }

    pin_clear(tiny_led);
  }

  if(tick > t2) { // update dht11
    t2 = tick+1500;
    pin_set(tiny_led);

    // Read DHT11 data
    tinudht_status = tinudht_read(&tinudht, TINUDHT_PIN);

    if(tinudht_status != TINUDHT_OK) {
      tinudht_last_temp = tinudht_last_hum = 0xFF;
      const char* buf = _ERR_MSG;
      oled.printStringTo(68, 2, buf);
      oled.printStringTo(68, 3, buf);
    }
    else
    {
      if(tinudht.temperature != tinudht_last_temp)
      {
        tinudht_last_temp = tinudht.temperature;

        // todo: add decimal digit
        oled.printFloatTo(68,2, ifloat32_t(tinudht.temperature, tinudht.temp_dec));
        oled.printStringTo(UNITS_POSITION, 2, DEG);
      }
      if(tinudht.humidity != tinudht_last_hum)
      {
        tinudht_last_hum = tinudht.humidity;

        oled.printNumberTo(68,3, tinudht.humidity);
        oled.printStringTo(UNITS_POSITION + 7, 3, "%");
      }
    }

    pin_clear(tiny_led);
  }

  if(tick > t3) { // thermometer animation
    t3 = tick+1000;
    static uint8_t st = 0;
    if(st == 0)
      oled.drawImage( img_thermometer_cold, 5,1, 5, 3 );
    else if (st == 1)
      oled.drawImage( img_thermometer_warm, 5,1, 5, 3 );
    else
      oled.drawImage( img_thermometer_hot,  5,1, 5, 3 );
    st = (st+1)%3;
  }

  // Set sleep mode to IDLE, this allows TIMER/COUNTER0 to keep running
  set_sleep_mode(SLEEP_MODE_IDLE);
  // Sleep until a timer interrupt
  sleep_mode();
}

int main(void)
{
  setup();
  while(true) loop();
}

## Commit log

2021-01-05 New features and bugfixes
    Fixed a bug in the way float number are converted to string
    Added a "float" class for better number manipulation
    [ds18b20.h, main.cpp]
2021-01-05 Add some basic power management
2021-01-09 Restructured oled driver to accept variable font sizes
    Added 8x16, 12x16 and 24x32 fonts
    Optimized i2c write routine on the display side
2021-01-09 Restructured main()
    I have separated routines in simple functions
    Divided the display into 2 screens,
    one for the ds18b20 and the other for the dht11 sensor.
    This way I can use a bigger font.
    Each screen also has new bitmaps.
    In the future, screen switch will be managed by a button instead of a timer.
2022-01-02 Replace the LED with a push button Added some basic functionallity for it to change screens instead of a timed sequence
    [app.h, main.c]
2022-01-03 Set the push button as an external interrupt
2022-01-04 Restructured main.c Move some display and sensors code to "app.c"
2022-01-04 Fix a button reading bug
    [main.c]
2022-01-05 Add 8ms and 50ms tickrates for SysTick interrupts. Default to 8ms. Couldn't get 50ms to work in 8MHz sysclock.
2022-01-05 Minor bugfix to screen drawing
    [app.h]
2022-01-05 Add 2.7V Brown-Out Detection in 1 and 8 MHz fuses
2022-01-05 Minor improvements in power management and button actions
2022-01-06 Fixed BOD-disable at sleep sequence. Fixed power-down sleep issue.
    [app.h, main.c]
2022-01-06 Add PCB and Case to Git
    [Tiny-thermomether.kicad_pcb, Tiny-thermomether.kicad_sch, Tiny-thermomether.sch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]
2022-09-10 Add battery module documentation reference
2022-09-10 Improve fixed point decimal manipulation fix/improve decimals representation in oled display also fix negative values in sensor reading

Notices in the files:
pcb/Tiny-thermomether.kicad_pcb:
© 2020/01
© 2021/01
